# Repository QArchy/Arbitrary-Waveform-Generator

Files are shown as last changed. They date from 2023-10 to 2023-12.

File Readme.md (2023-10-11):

# ***Курсовая работа на тему "Генератор Сигналов произвольной формы"***
***Выполнил студент группы РЛ6-61 Худяков А.С.***

An old rock in the desert

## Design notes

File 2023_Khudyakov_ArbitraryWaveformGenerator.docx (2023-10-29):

Московский государственный технический университет им. Н.Э. Баумана

Факультет «Радиоэлектроника и лазерная техника (РЛ)»

Кафедра «Технология приборостроения (РЛ6)»

Курсовая работа на тему

«Генератор сигналов произвольной формы»

Выполнил ст. группы РЛ6-71

Худяков А. С.

Преподаватель Семеренко Д. А.

Москва, 2023

# Введение

В данной работе будет решена задача создания генератора сигналов произвольной формы. В устройстве реализована генерация стандартных форм сигналов (синусоидальный, прямоугольный, треугольный и пилообразный) и белого шума. Пользователю будет доступна загрузка формы, частоты и амплитуды сигнала через программу для компьютера, которая, в свою очередь, передает управляющие сигналы на устройство путем передачи данных по USART.

Генераторы сигналов произвольной формы имеет широкий спектр применений в различных областях: от радио и телепередачи до медицинской аппаратуры. Остановимся на некоторых из них:

1) в области радиопередачи и радиоприема такое устройство может применятся для отладки и тестирования аппаратуры, управляемой сигналами строго определенной формы (переключение каналов телевизора, машина на радиоуправлении, беспилотные летательные аппараты);
2) в области медицины генерирование сигналов различной конфигурации может быть использовано для исследования человеческого тела (томографы, электрокардиографы, аппараты УЗИ);
3) в военной области генерирование сигналов может быть применено для вывода из строя радиокоммуникации на некоторой площади, создания поддельных радиосообщений.

При разработке генератора сигналов произвольной формы необходимо решить следующие задачи и проблемы:

1) синхронизация частоты передачи с компьютера управляющих сигналов через USART с частотой приема ПЛИС.
2) реализация прямоугольной, треугольной и пилообразной формы сигнала. Эта задача решается с помощью простого счетчика, выходы которого подсоединяются к ЦАП;
3) реализация синусоидальной форму сигнала. Эта задача решается с либо с помощью непосредственно вычисления синуса как функции, либо используя предварительно рассчитанную таблицу значений;
4) генерация белого шума. При разработке алгоритма генерации белого шума нужно учитывать его быстродействие и сложность;
5) изменение частоты сигнала. Частота выходного сигнала ограничивается частотой используемого ЦАП, для динамического изменения частоты генерации сигнала можно масштабировать уже вычисленные значения сигналов;
6) изменение амплитуды сигнала. Амплитуду выходного сигнала можно менять с помощью операционного усилителя с обратной связью и транзисторами, работающими в ключевом режиме для подстройки коэффициента усиления.

Цель исследования – сравнение ЦАП PCF8591 (Максимальная частота = 10 КГц) с R-2R цепочкой.

PCF8591 Quad 8-Bit ADC + 8-Bit DAC (0x48 - 0x4F I2C addreses)

// как можно использовать полученные результаты в будущем?

# Глава 1

В этой главе будут приведены различный способы реализации отдельных компонентов устройства и соответствующих алгоритмов.

Передача управляющих сигналов на ПЛИС может осуществляться несколькими способами:

1) с помощью программы-терминала типа HTerm,
2) подключения клавиатуры к ПЛИС,
3) управления с помощью кнопок на отладочной плате.

Генерация сигналов синусоидальной, прямоугольной, треугольной и пилообразной формы может осуществляться масштабированием уже вычисленных значений или программной реализацией алгоритма расчета значения функции в каждый момент времени.

Создание белого шума требует реализации одного из соответствующих алгоритмов, основанных на одном из множества способов генерации случайных чисел, отличающихся лишь степенью использования памяти и вычислительных мощностей.

# Глава 2

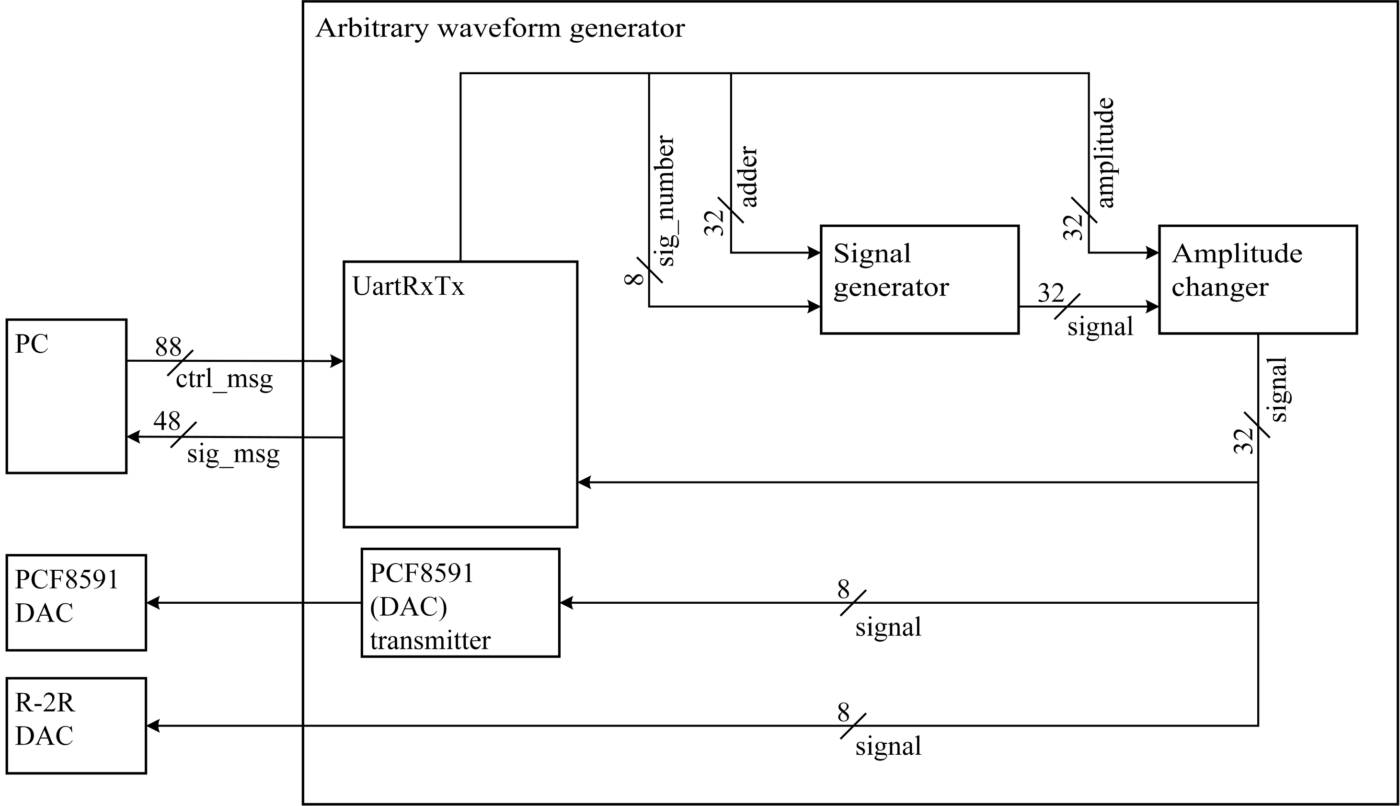
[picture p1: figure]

Рис. 1 – Функциональная схема устройства.

Описание модуля UartRxTx: модуль отвечает за прием и передачу данных между программой на компьютере и ПЛИС.

Рис. 2 – Функциональная схема модуля UartRxTx.

Описание модуля UartRx: модуль отвечает за прием и передачу данных между программой на компьютере и ПЛИС.

Описание модуля UartTx: модуль отвечает за прием и передачу данных между программой на компьютере и ПЛИС.

Структура управляющей команды ctrl_msg:

Бит | 1 | 2 | | 3 | | 4 | | 5 | | 6 | | | 7 | | 8
Сообщение | SOM (start of message)
Бит | 9 | | 10 | | 11 | | 12 | | 13 | | 14 | 15 | | 16
Сообщение | sig_number
Бит | 17 – 48
Сообщение | adder
Бит | 49 – 80
Сообщение | amplitude

Бит | 81 | 82 | 83 | 84 | 85 | 86 | 87 | 88
Сообщение | EOM (end of message)

Кодограмма управляющей команды ctrl_msg:

Имя | Принимаемые значения | Назначение
SOM (start of message) | ASCII – 's' Binary – 0b01110011 | Индикатор начала сообщения
sig_number | 0b000 | Выбор синусоидального сигнала
| 0b001 | Выбор сигнала типа "шум"
| 0b010 | Выбор сигнала «треугольного» типа
| 0b011 | Выбор сигнала типа "меанд"
| 0b100 | Выбор сигнала типа "пила"
| 0b101 | Выбор сигнала типа "рампа"
adder | 0..2³² | Настройка частоты выходного сигнала
amplitude | 0..2³² | Настройка амплитуды выходного сигнала
EOM (end of message) | ASCII – 'e' Binary – 0b01100101 | Индикатор конца сообщения

Структура выходной команды sig_msg:

Бит | 1 | 2 | 3 | 4 | 5 | 6 | 7 | 8
Сообщение | SOM (start of message)
Бит | 9 – 40
Сообщение | signal
Бит | 41 | 42 | 43 | 44 | 45 | 46 | 47 | 48
Сообщение | EOM (end of message)

Кодограмма выходной команды sig_msg:

Имя | Принимаемые значения | Назначение
SOM (start of message) | ASCII – 's' Binary – 0b01110011 | Индикатор начала сообщения
signal | 0..2³² | Выходной сигнал
EOM (end of message) | ASCII – 'e' Binary – 0b01100101 | Индикатор конца сообщения

Описание модуля SignalGenerator: модуль производит генерацию выбранного командой sig_number сигнала с заданным коэффициентом частоты adder. Генерация сигнала происходит в диапазоне частот от 1 Гц до 200 МГц.

Описание модуля AmplitudeChanger: модуль производит настройку амплитуды выходного сигнала с помощью заданного коэффициента амплитуды amplitude. Настройка амплитуды сигнала происходит в диапазоне от 0 В до максимального значения, заданного в программе для компьютера и до максимального напряжения выводов ПЛИС.

Описание модуля PCF8591Transmitter: модуль отвечает за передачу сигнала на микросхему PCF8591. Максимальная частота выходного сигнала равна 11.1 КГц. Это накладывает следующее ограничение: частота генерации сигнала должна лежать в пределах от 1 до 11.1 КГц, иначе будут появляться визуальные ошибки выходного сигнала.

// Схема с ПЛИС + операционный усилитель на выходе ЦАП

Рис. 2 – Принципиальная электрическая схема устройства.

# Глава 3

В этой главе будут приведены основные алгоритмы работы ПЛИС и описаны основные функции ПЛИС.

1) Модуль UART receiver принимает 8-битное слово и подает его на вход модуля UART decoder.
2) Модуль UART decoder принимает 4 слова по 8 бит и декодирует их в набор команд: sig_number, frequency, freq_change, amplitude, ampl_change.

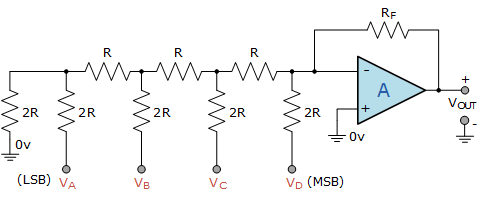
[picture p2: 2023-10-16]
r-2r.png

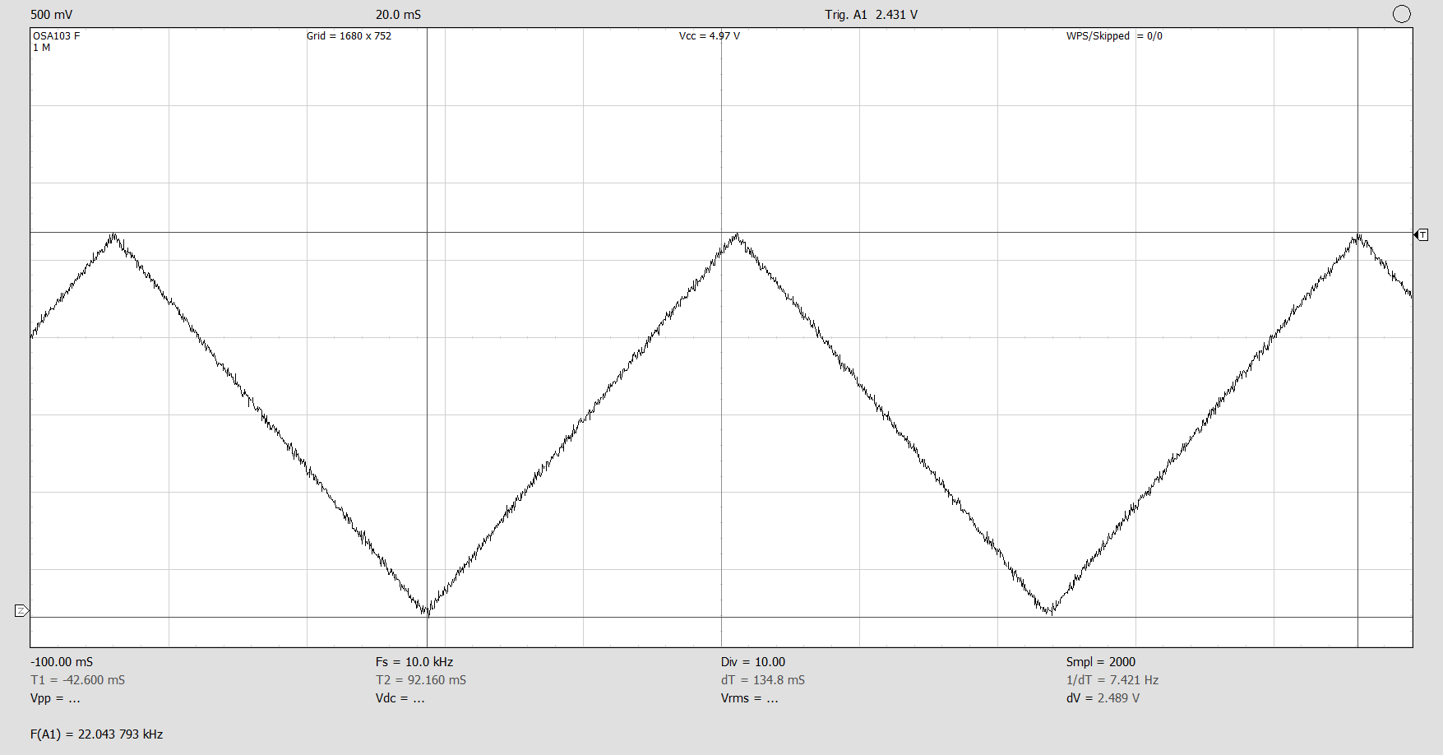
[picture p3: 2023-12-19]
triangle_11.1kHz.png

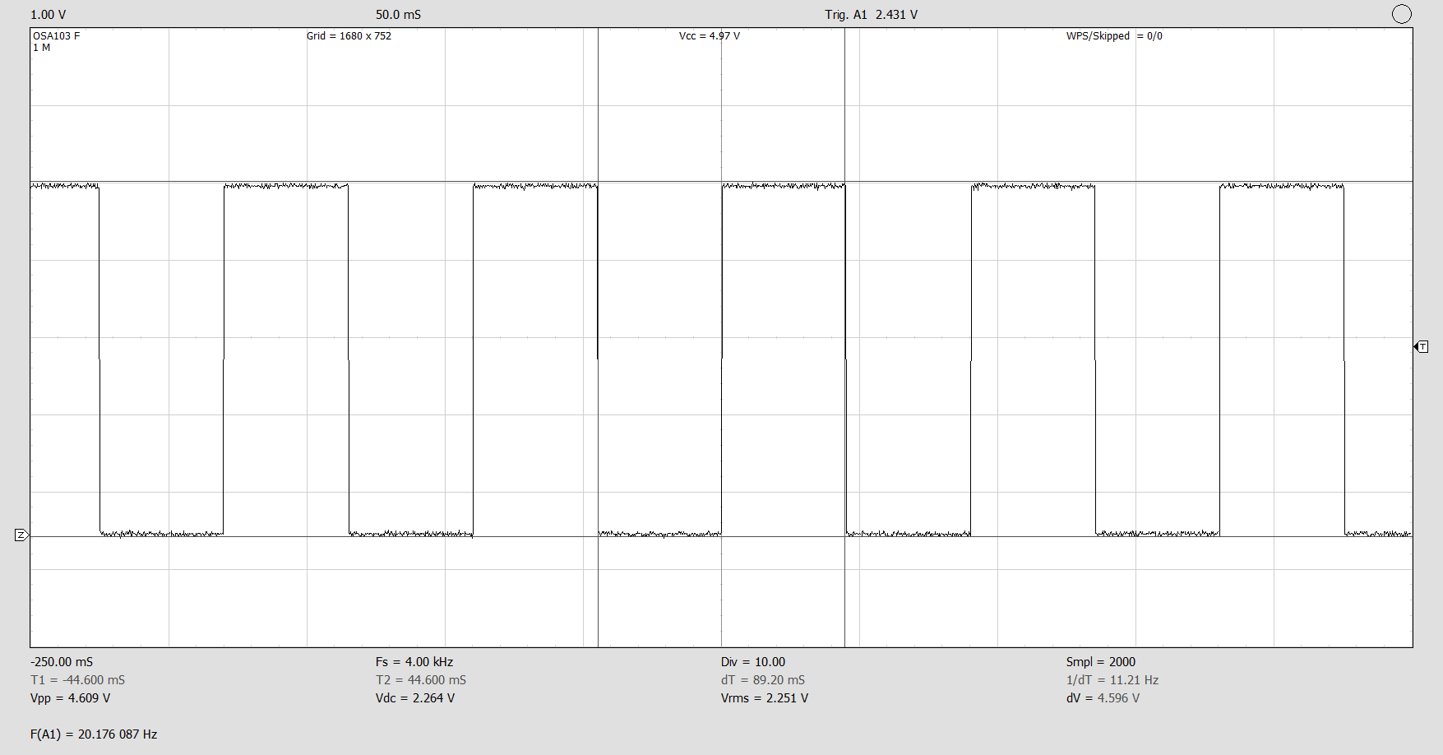
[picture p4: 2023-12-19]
meandr_11.1kHz.png

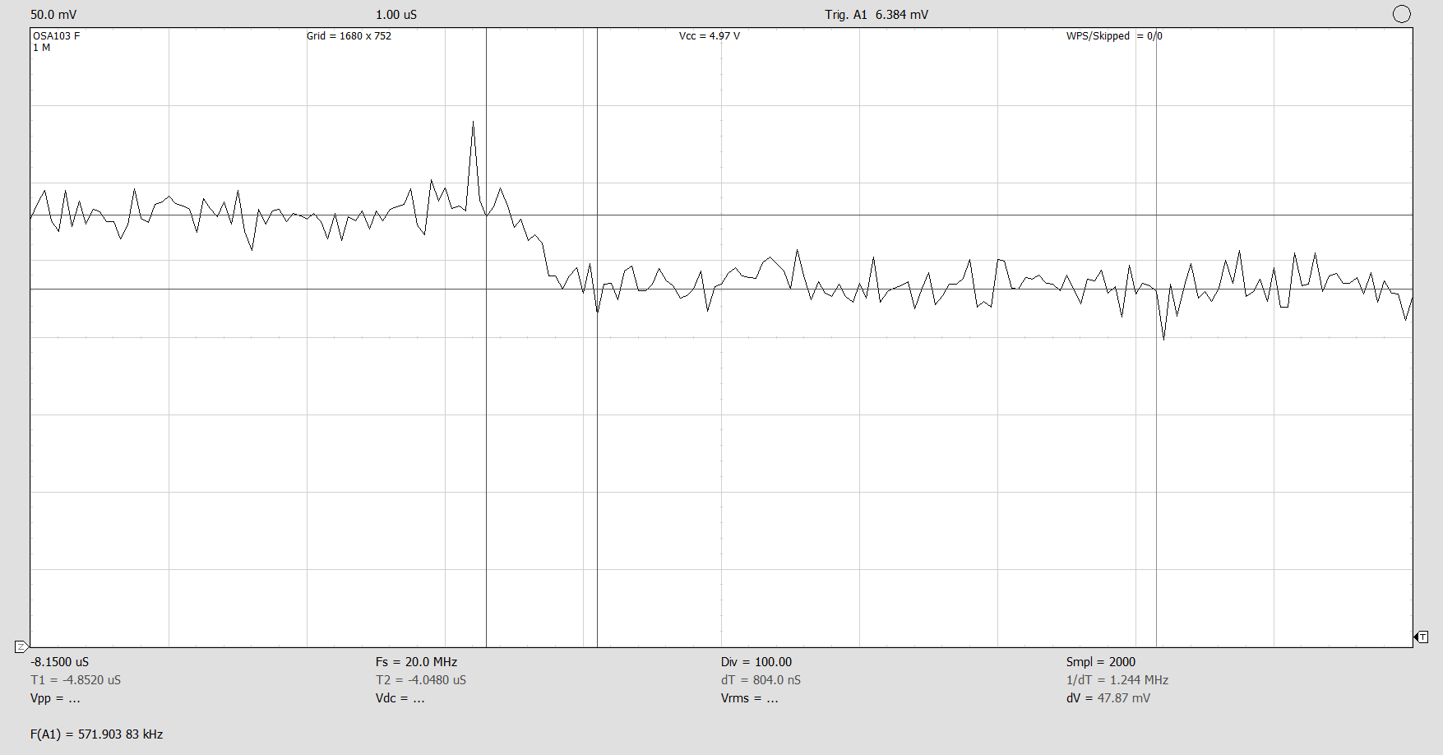
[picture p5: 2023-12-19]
switch.png

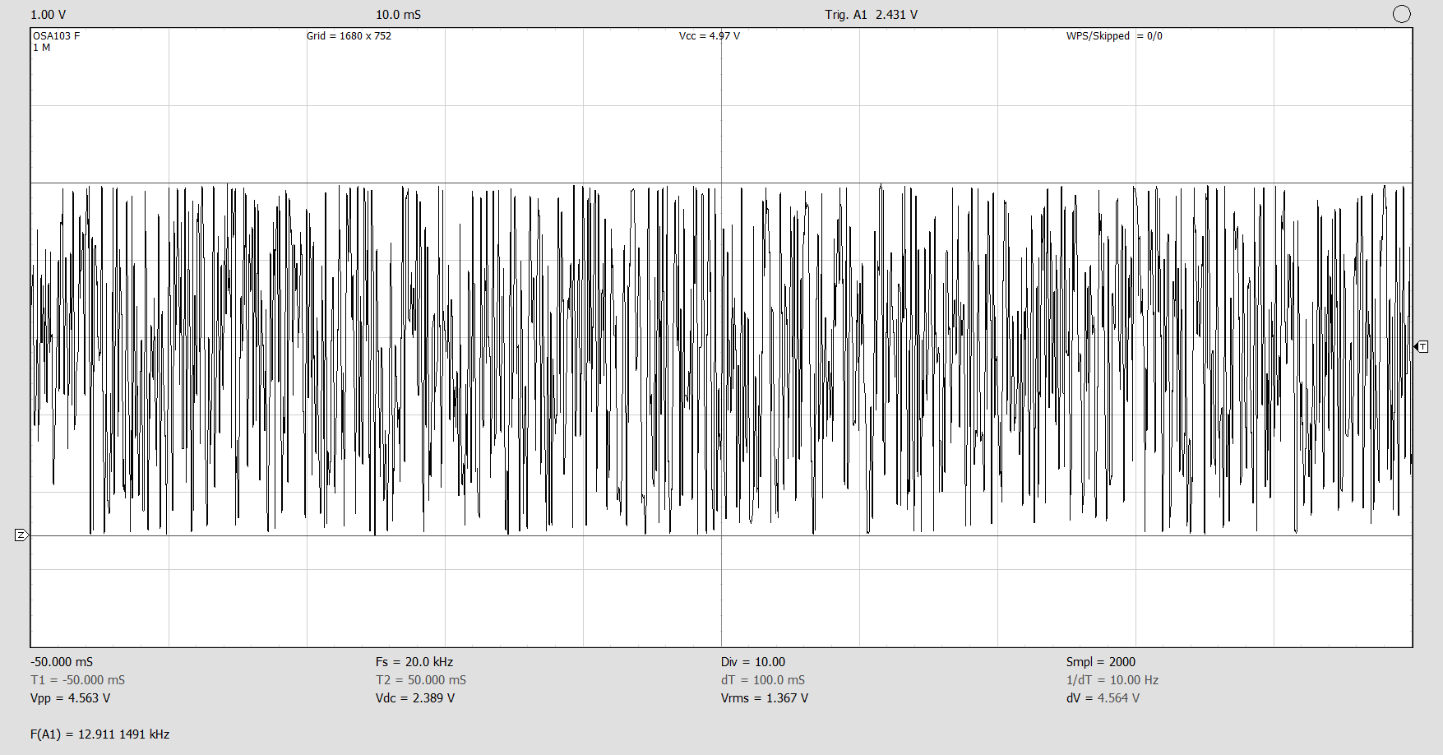
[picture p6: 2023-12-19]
noise_11.1kHz.png

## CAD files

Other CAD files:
QuartusProject/dbg/stp2.stp
QuartusProject/project/stp2.stp

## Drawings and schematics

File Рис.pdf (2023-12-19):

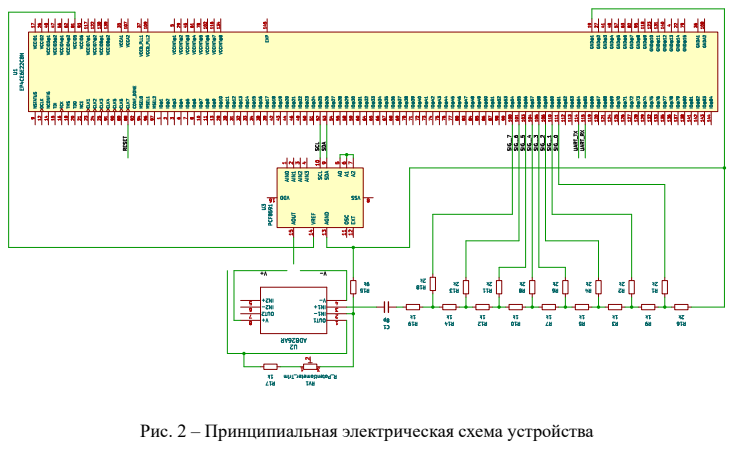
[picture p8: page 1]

Рис. 2 – Принципиальная электрическая схема устройства

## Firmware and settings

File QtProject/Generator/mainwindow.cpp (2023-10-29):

#include "mainwindow.h"
#include "ui_mainwindow.h"
#include <QDebug>

MainWindow::MainWindow(QWidget *parent): QMainWindow(parent), ui(new Ui::MainWindow) {
    ui->setupUi(this);

    uartConfigDialog = new UartConfigDialog();
    dds = new DDS();
    serialManager = new SerialManager();

    // window uartConfig
    QObject::connect(ui->actionComPortConfig, SIGNAL(triggered(bool)), this, SLOT(slot_showUartConfig(bool)));
    QObject::connect(uartConfigDialog, SIGNAL(sig_uartConfig(uartConfig)), this, SLOT(slot_uartGetConfig(uartConfig)));

    // Frequency slots
    QObject::connect (ui->Freq_1Hz_SpinBox, SIGNAL(textChanged(const QString&)), this, SLOT(slot_frequencyTextChanged(const QString&)));
    QObject::connect (ui->Freq_10Hz_SpinBox, SIGNAL(textChanged(const QString&)), this, SLOT(slot_frequencyTextChanged(const QString&)));
    QObject::connect (ui->Freq_100Hz_SpinBox, SIGNAL(textChanged(const QString&)), this, SLOT(slot_frequencyTextChanged(const QString&)));
    QObject::connect (ui->Freq_1KHz_SpinBox, SIGNAL(textChanged(const QString&)), this, SLOT(slot_frequencyTextChanged(const QString&)));
    QObject::connect (ui->Freq_10KHz_SpinBox, SIGNAL(textChanged(const QString&)), this, SLOT(slot_frequencyTextChanged(const QString&)));
    QObject::connect (ui->Freq_100KHz_SpinBox, SIGNAL(textChanged(const QString&)), this, SLOT(slot_frequencyTextChanged(const QString&)));
    QObject::connect (ui->Freq_1MHz_SpinBox, SIGNAL(textChanged(const QString&)), this, SLOT(slot_frequencyTextChanged(const QString&)));
    QObject::connect (ui->Freq_10MHz_SpinBox, SIGNAL(textChanged(const QString&)), this, SLOT(slot_frequencyTextChanged(const QString&)));

    // Amplitude slots
    QObject::connect (ui->VPercentSpinBox, SIGNAL(textChanged(const QString&)), this, SLOT(slot_amplitudeTextChanged(const QString&)));

    // Wafeform slots
    QObject::connect (ui->SinRadioBtn, SIGNAL(clicked(bool)), this, SLOT(slot_waveformCheckChanged(bool)));
    QObject::connect (ui->NoiseRadioBtn, SIGNAL(clicked(bool)), this, SLOT(slot_waveformCheckChanged(bool)));
    QObject::connect (ui->TriangleRadioBtn, SIGNAL(clicked(bool)), this, SLOT(slot_waveformCheckChanged(bool)));
    QObject::connect (ui->RectangleRadioBtn, SIGNAL(clicked(bool)), this, SLOT(slot_waveformCheckChanged(bool)));
    QObject::connect (ui->SawRadioBtn, SIGNAL(clicked(bool)), this, SLOT(slot_waveformCheckChanged(bool)));
    QObject::connect (ui->RampRadioBtn, SIGNAL(clicked(bool)), this, SLOT(slot_waveformCheckChanged(bool)));
}

MainWindow::~MainWindow() {
    delete serialManager;
    delete dds;
    delete uartConfigDialog;
    delete ui;
}

void MainWindow::slot_frequencyTextChanged(const QString& str) {
    Q_UNUSED(str);
    QString newFrequencyStr =
        ui->Freq_10MHz_SpinBox->text() + ui->Freq_1MHz_SpinBox->text() +
        ui->Freq_100KHz_SpinBox->text() + ui->Freq_10KHz_SpinBox->text() + ui->Freq_1KHz_SpinBox->text() +
        ui->Freq_100Hz_SpinBox->text() + ui->Freq_10Hz_SpinBox->text() + ui->Freq_1Hz_SpinBox->text();
    dds->setAdder(newFrequencyStr.toDouble());
    ui->adderLineEdit->setText(QString::number(dds->getAdder()));
    ui->adderIntLineEdit->setText(QString::number(dds->getAdderInt()));
    serialManager->write(dds->formUartCommand());
}

void MainWindow::slot_amplitudeTextChanged(const QString& str) {
    dds->setOutputAmplitude(str.toDouble());
    ui->CurrentVoutLineEdit->setText(QString::number(dds->getCurrentOutputAmplitude()));
    serialManager->write(dds->formUartCommand());
    qDebug() << "Output amplitude: " << dds->getOutputAmplitude();
}

void MainWindow::slot_waveformCheckChanged(bool checked) {
    Q_UNUSED(checked);
    if (ui->SinRadioBtn->isChecked()) {
        dds->setWave(WaveForm::Sin);
    } else if (ui->NoiseRadioBtn->isChecked()) {
        dds->setWave(WaveForm::Noise);
    } else if (ui->TriangleRadioBtn->isChecked()) {
        dds->setWave(WaveForm::Triangle);
    } else if (ui->RectangleRadioBtn->isChecked()) {
        dds->setWave(WaveForm::Rect);
    } else if (ui->SawRadioBtn->isChecked()) {
        dds->setWave(WaveForm::Saw);
    } else if (ui->RampRadioBtn->isChecked()) {
        dds->setWave(WaveForm::Ramp);
    }
    serialManager->write(dds->formUartCommand());
    qDebug() << "Dds wave: " << dds->getWave();
}

void MainWindow::slot_showUartConfig(bool checked) {
    Q_UNUSED(checked);
    uartConfigDialog->updatePortNames();
    uartConfigDialog->open();
}

void MainWindow::slot_uartGetConfig(uartConfig uartConf) {
    bool portOpened = serialManager->configurePort(uartConf);
    Q_UNUSED(portOpened);
    qDebug() << "Port opened: " << portOpened;
}

void MainWindow::on_MaxVoutLineEdit_textChanged(const QString &arg1) {
    dds->setMaxOutputAmplitude(arg1.toDouble());
    dds->setOutputAmplitude(ui->VPercentSpinBox->text().toDouble());
    ui->CurrentVoutLineEdit->setText(QString::number(dds->getCurrentOutputAmplitude()));
    serialManager->write(dds->formUartCommand());
    qDebug() << "Output amplitude: " << dds->getOutputAmplitude();
}

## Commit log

2023-10-11 test end
    ui blocks (programm not responding) when getting readyRead() signal from UART
2023-10-14 restructure quartus project
    [stp2.stp]
2023-10-16 created simple writing app
    [stp2.stp]
2023-10-16 prepare i2c_testBench for work
2023-10-23 Fixed uart transmission error
    [stp2.stp]
2023-10-23 iic done
    [stp2.stp]
2023-10-29 gave up on oscilloscope, qt app done, FPGA project done
    TODO:
    1) Documentation
    [stp2.stp]
